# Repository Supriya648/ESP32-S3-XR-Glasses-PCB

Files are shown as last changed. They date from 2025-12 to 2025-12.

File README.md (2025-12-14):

# ESP32-S3-XR-Glasses-PCB
Custom PCB with ESP32-S3 camera module for AI/XR glasses
# ESP32-S3 Camera Resolution Performance Demo

## Project Overview
This project demonstrates video capture using an ESP32-S3-based camera system at multiple
resolutions to study trade-offs between image quality, frame rate, and memory usage.
The system is intended for compact, wearable AI/XR applications.

## Hardware
- ESP32-S3 MCU
- Camera module (OV2640 / OV3660)
- External PSRAM (on-chip)
- USB power and programming interface

## Software
- Arduino framework
- ESP32 camera driver

## Demo Description
Video clips were captured at different resolutions supported by the ESP32-S3:
- 320×240 (QVGA)
- 640×480 (VGA)
- 800×600 (SVGA)

Each configuration was evaluated for visual quality and approximate frame rate.

## Results
Lower resolutions achieved higher frame rates and stability, while higher resolutions
provided improved image detail at the cost of increased memory usage and reduced frame rate.

## Repository Structure
- firmware/: ESP32-S3 camera firmware
- hardware/: Schematic and PCB layout
- results/: Recorded video samples and performance logs
- report/: Final project report (PDF)

## Demo Video
YouTube link: [https://youtu.be/lZMv0Ex0UyA]

## Author
Supriya Ramaswamy  
EECE – Wireless & Network Engineering

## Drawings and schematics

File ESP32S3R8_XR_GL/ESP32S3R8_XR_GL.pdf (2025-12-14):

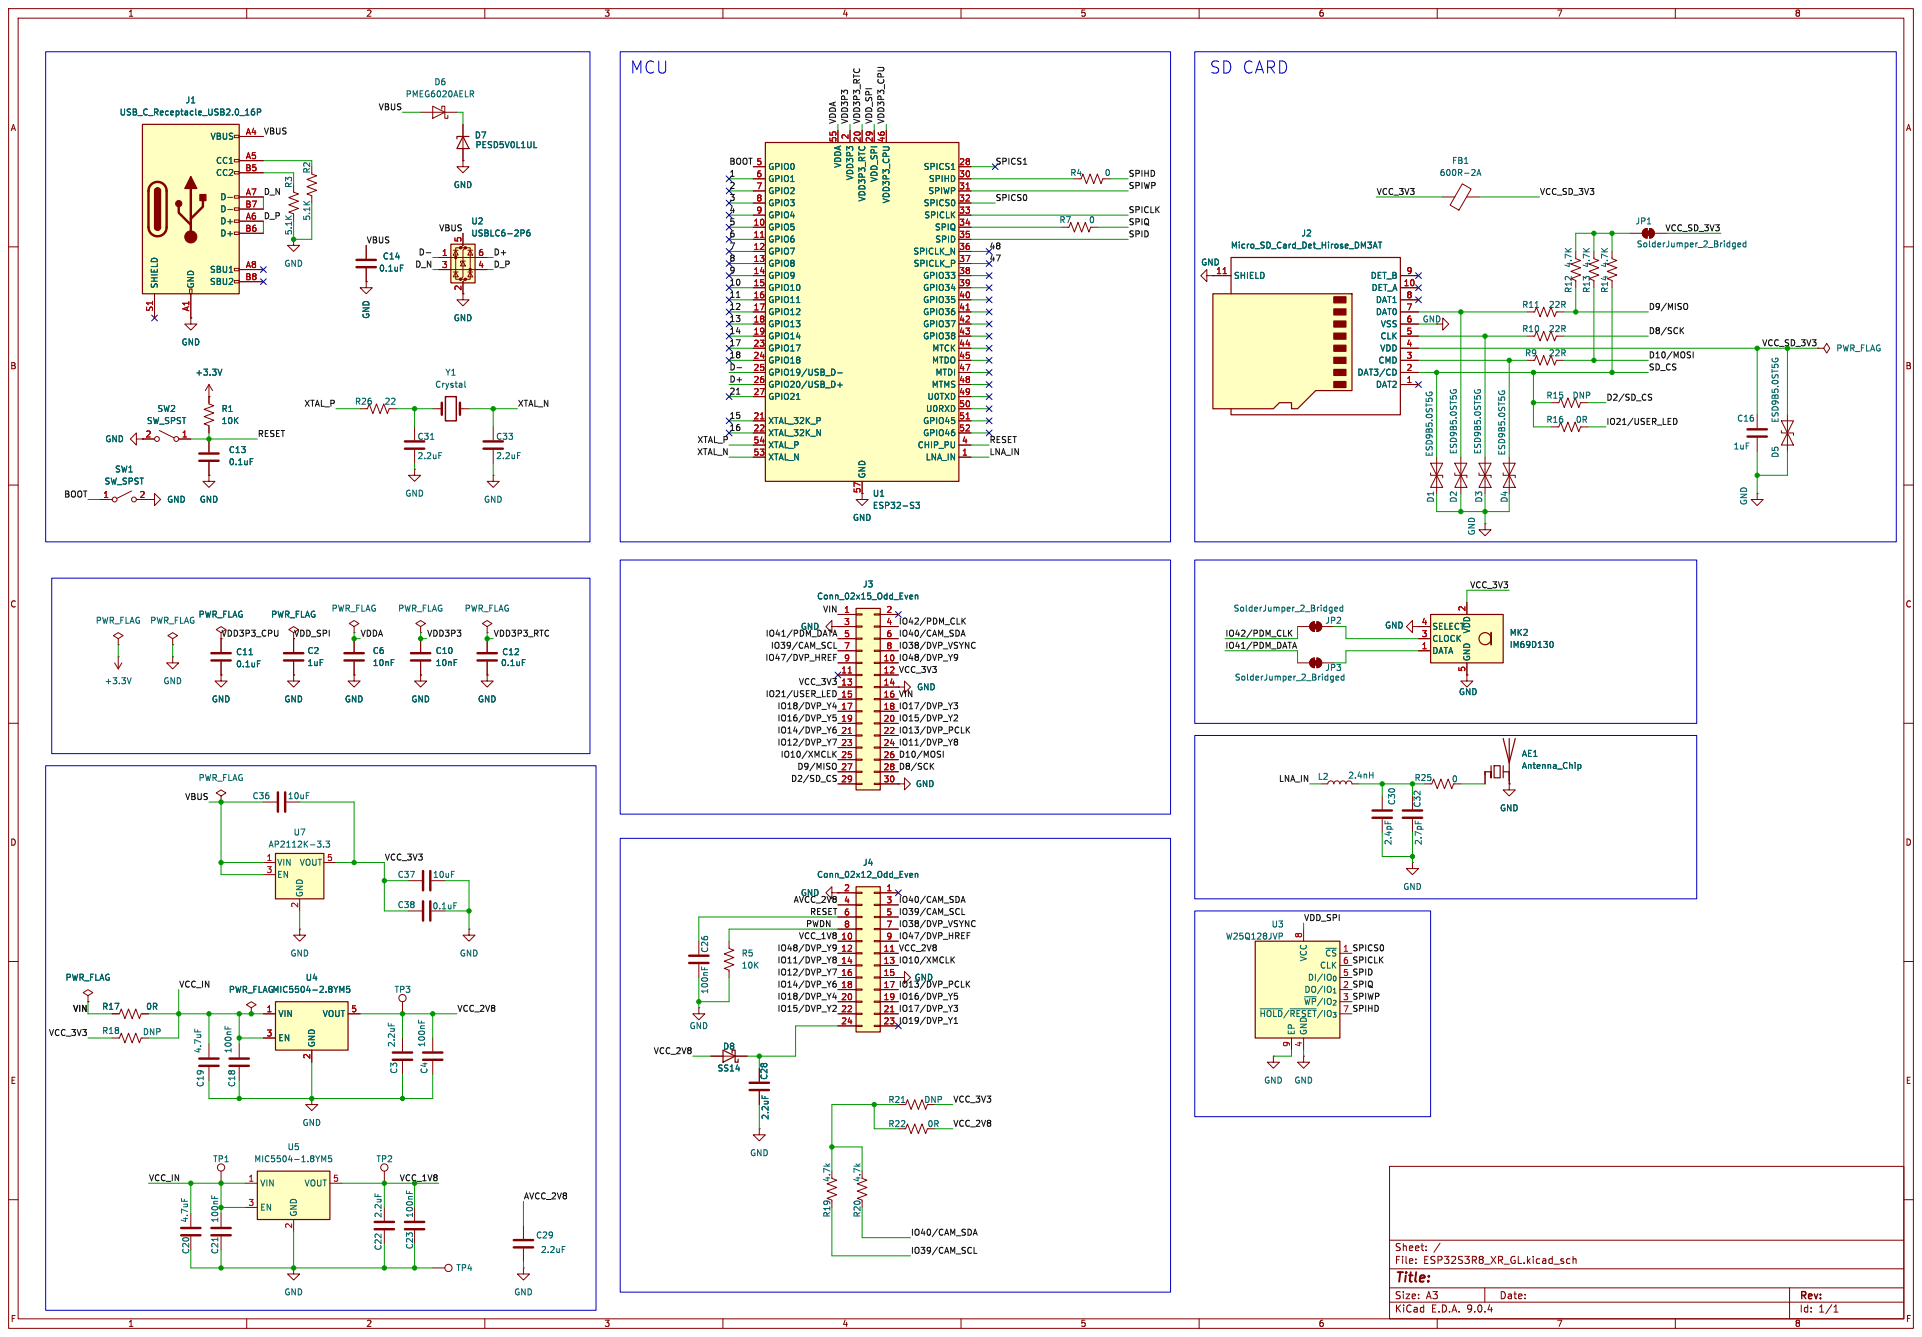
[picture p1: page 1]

2 VDD3P3_RTC 20 GND 57 VDD_SPI 29 VDD3P3_CPU 46 SPICS1 28 SPIHD 30 SPIWP 31 SPICS0 32 SPICLK 33 SPIQ 34 SPID 35 SPICLK_P 37 GPIO33 38 GPIO34 39 GPIO35 40 GPIO36 41 GPIO37 42 GPIO38 43 MTCK 44 MTDI 47 MTMS 48 U0TXD 49 U0RXD 50 GPIO46 52 CHIP_PU 4

5 SELECT 4 CLOCK 3 DATA 1 GND

2 VOUT 5 U4 MIC5504-2.8YM5 C19 4.7uF C18 100nF C3 2.2uF C4 100nF C21 100nF C23 100nF VIN 1 EN 3 GND

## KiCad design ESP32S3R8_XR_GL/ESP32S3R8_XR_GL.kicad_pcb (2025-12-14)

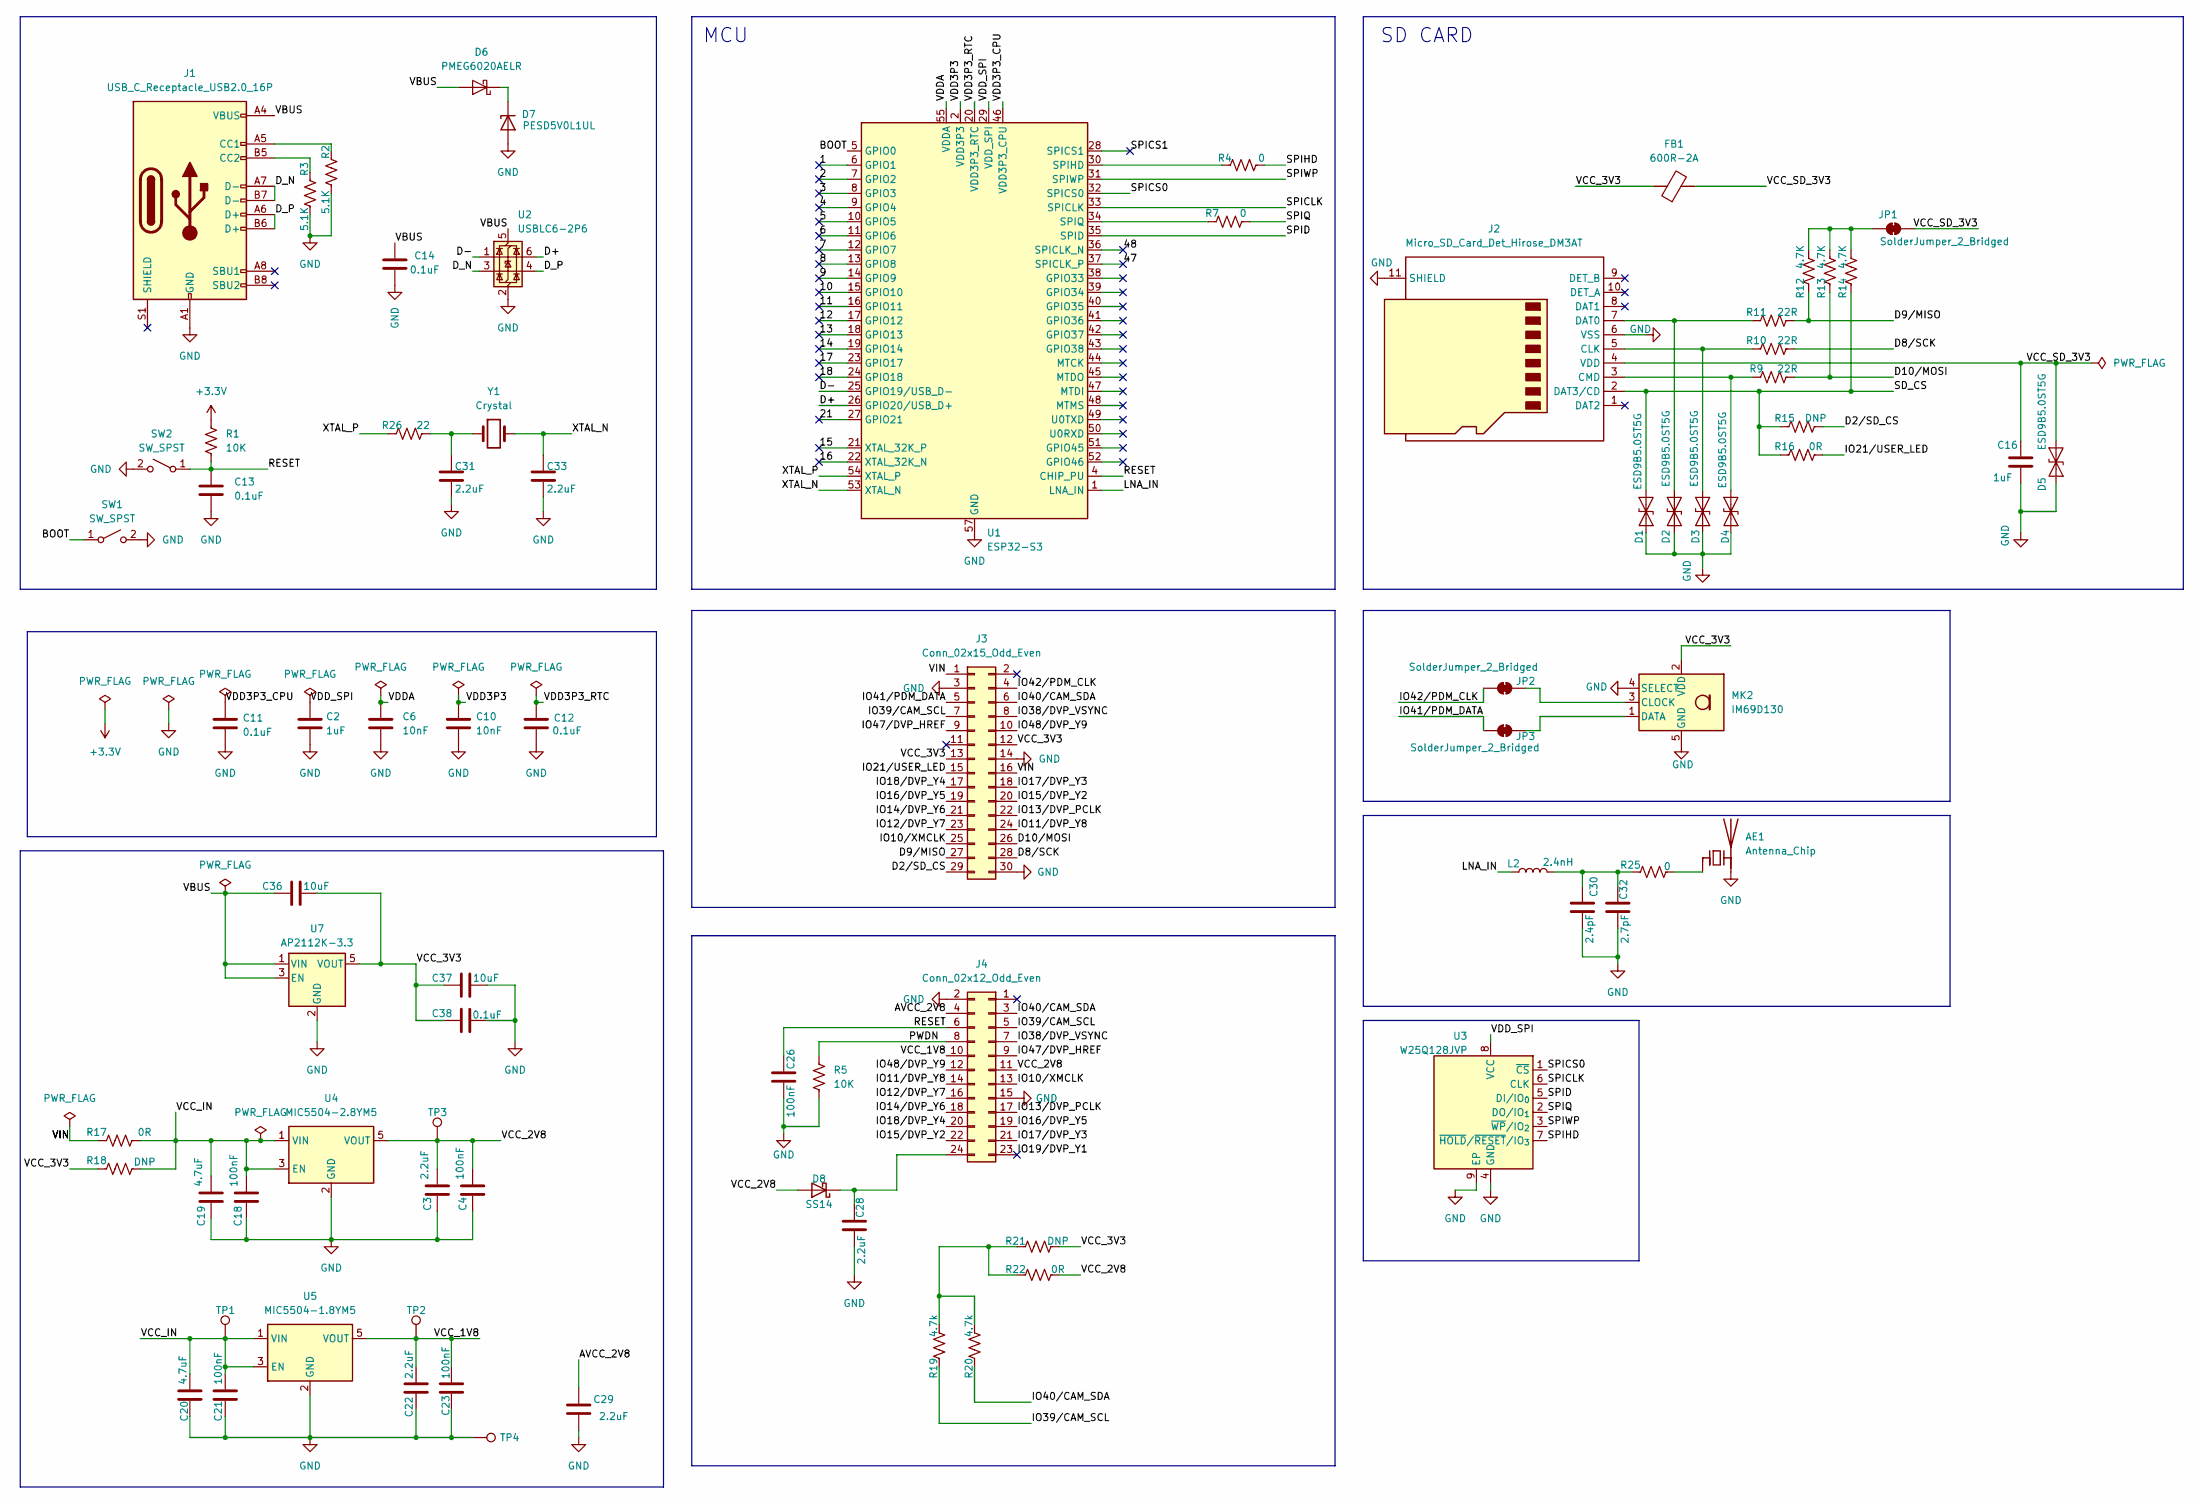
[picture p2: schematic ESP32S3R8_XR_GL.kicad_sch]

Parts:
AE1: Antenna_Chip; Johanson_2450AT18x100
C2, C16: 1uF; C_0603_1608Metric
C3, C22, C28, C29, C31, C33: 2.2uF; C_0603_1608Metric
C4, C18, C21, C23, C26: 100nF; C_0402_1005Metric
C6, C10: 10nF; C_0402_1005Metric
C11, C12, C13, C14, C38: 0.1uF; C_0402_1005Metric
C19, C20: 4.7uF; C_0603_1608Metric
C30: 2.4pF; C_0402_1005Metric
C32: 2.7pF; C_0402_1005Metric
C36, C37: 10uF; C_0805_2012Metric
D1, D2, D3, D4, D5: ESD9B5.0ST5G; D_SOD-923
D6: PMEG6020AELR; Nexperia_CFP3_SOD-123W
D7: PESD5V0L1UL; D_SOD-882
D8: SS14; D_SMA
FB1: 600R-2A; L_0805_2012Metric
J1: USB_C_Receptacle_USB2.0_16P; USB_C_Receptacle_GCT_USB4085
J2: Micro_SD_Card_Det_Hirose_DM3AT; microSD_HC_Hirose_DM3AT-SF-PEJM5
J3: Conn_02x15_Odd_Even; PinHeader_2x15_P2.54mm_Vertical
J4: Conn_02x12_Odd_Even; PinHeader_2x12_P2.54mm_Vertical
JP1, JP2, JP3: SolderJumper_2_Bridged; SolderJumper-2_P1.3mm_Bridged_RoundedPad1.0x1.5mm
L2: 2.4nH; L_0402_1005Metric
MK2: IM69D130; Infineon_PG-LLGA-5-1
R1, R5: 10K; R_0402_1005Metric
R2, R3: 5.1K; R_0402_1005Metric
R4, R7, R25: 0; R_0402_1005Metric
R9, R10, R11: 22R; R_0402_1005Metric
R12, R13, R14: 4.7K; R_0402_1005Metric
R15, R18, R21: DNP; R_0402_1005Metric
R16, R17, R22: 0R; R_0402_1005Metric
R19, R20: 4.7k; R_0402_1005Metric
R26: 22; R_0402_1005Metric
SW1, SW2: SW_SPST; SW_SPST_SKQG_WithStem
TP1, TP2, TP3, TP4: TestPoint; TestPoint_Pad_D1.0mm
U1: ESP32-S3; QFN-56-1EP_7x7mm_P0.4mm_EP4x4mm
U2: USBLC6-2P6; SOT-666
U3: W25Q128JVP; WSON-8-1EP_6x5mm_P1.27mm_EP3.4x4.3mm
U4: MIC5504-2.8YM5; SOT-23-5
U5: MIC5504-1.8YM5; SOT-23-5
U7: AP2112K-3.3; SOT-23-5
Y1: Crystal; Crystal_SMD_3225-4Pin_3.2x2.5mm

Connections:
+3.3V: R1.1
/1: U1.6 (GPIO1)
/2: U1.7 (GPIO2)
/3: U1.8 (GPIO3)
/4: U1.9 (GPIO4)
/5: U1.10 (GPIO5)
/6: U1.11 (GPIO6)
/7: U1.12 (GPIO7)
/8: U1.13 (GPIO8)
/9: U1.14 (GPIO9)
/10: U1.15 (GPIO10)
/11: U1.16 (GPIO11)
/12: U1.17 (GPIO12)
/13: U1.18 (GPIO13)
/14: U1.19 (GPIO14)
/15: U1.21 (XTAL_32K_P)
/16: U1.22 (XTAL_32K_N)
/17: U1.23 (GPIO17)
/18: U1.24 (GPIO18)
/21: U1.27 (GPIO21)
/47: U1.37 (SPICLK_P)
/48: U1.36 (SPICLK_N)
/AVCC_2V8: C29.1, J4.4
/BOOT: SW1.1 (A), U1.5 (GPIO0)
/D2/SD_CS: J3.29, R15.2
/D8/SCK: J3.28, R10.2
/D9/MISO: J3.27, R11.2, R12.1
/D10/MOSI: J3.26, R9.2, R13.1
/D+: U1.26 (GPIO20/USB_D+), U2.6 (I/O1)
/D-: U1.25 (GPIO19/USB_D-), U2.1 (I/O1)
/D_N: J1.A7 (D-), J1.B7 (D-), U2.3 (I/O2)
/D_P: J1.A6 (D+), J1.B6 (D+), U2.4 (I/O2)
/IO10/XMCLK: J3.25, J4.13
/IO11/DVP_Y8: J3.24, J4.14
/IO12/DVP_Y7: J3.23, J4.16
/IO13/DVP_PCLK: J3.22, J4.17
/IO14/DVP_Y6: J3.21, J4.18
/IO15/DVP_Y2: J3.20, J4.22
/IO16/DVP_Y5: J3.19, J4.19
/IO17/DVP_Y3: J3.18, J4.21
/IO18/DVP_Y4: J3.17, J4.20
/IO19/DVP_Y1: J4.23
/IO21/USER_LED: J3.15, R16.2
/IO38/DVP_VSYNC: J3.8, J4.7
/IO39/CAM_SCL: J3.7, J4.5, R19.1
/IO40/CAM_SDA: J3.6, J4.3, R20.1
/IO41/PDM_DATA: J3.5, JP3.2 (B)
/IO42/PDM_CLK: J3.4, JP2.2 (B)
/IO47/DVP_HREF: J3.9, J4.9
/IO48/DVP_Y9: J3.10, J4.12
/LNA_IN: L2.1, U1.1 (LNA_IN)
/PWDN: J4.8, R5.1
/RESET: C13.1, C26.1, J4.6, R1.2, SW2.1 (A), U1.4 (CHIP_PU)
/SD_CS: D1.2 (A2), J2.2 (DAT3/CD), R14.1, R15.1, R16.1
/SPICLK: U1.33 (SPICLK), U3.6 (CLK)
/SPICS0: U1.32 (SPICS0), U3.1 (~CS)
/SPICS1: U1.28 (SPICS1)
/SPID: U1.35 (SPID), U3.5 (DI/IO_{0})
/SPIHD: R4.2, U3.7 (~HOLD/~RESET/IO_{3})
/SPIQ: R7.2, U3.2 (DO/IO_{1})
/SPIWP: U1.31 (SPIWP), U3.3 (~WP/IO_{2})
/VBUS: C14.1, C36.1, D6.2 (A), J1.A4 (VBUS), J1.A9 (VBUS), J1.B4 (VBUS), J1.B9 (VBUS), U2.5 (VBUS), U7.1 (VIN), U7.3 (EN)
/VCC_1V8: C22.1, C23.1, J4.10, TP2.1, U5.5 (VOUT)
/VCC_2V8: C3.1, C4.1, D8.2 (A), J4.11, R22.2, TP3.1, U4.5 (VOUT)
/VCC_3V3: C36.2, C37.1, C38.1, FB1.1, J3.12, J3.13, MK2.2 (VDD), R18.1, R21.2, U7.5 (VOUT)
/VCC_IN: C18.1, C19.1, C20.1, C21.1, R17.2, R18.2, TP1.1, U4.1 (VIN), U4.3 (EN), U5.1 (VIN), U5.3 (EN)
/VCC_SD_3V3: C16.1, D5.2 (A2), FB1.2, J2.4 (VDD), JP1.2 (B)
/VDD3P3: C10.1, U1.2 (VDD3P3), U1.3 (VDD3P3)
/VDD3P3_CPU: C11.1, U1.46 (VDD3P3_CPU)
/VDD3P3_RTC: C12.1, U1.20 (VDD3P3_RTC)
/VDDA: C6.1, U1.55 (VDDA), U1.56 (VDDA)
/VDD_SPI: C2.1, U1.29 (VDD_SPI), U3.8 (VCC)
/VIN: J3.1, J3.16, R17.1
/XTAL_N: C33.1, U1.53 (XTAL_N), Y1.2
/XTAL_P: R26.1, U1.54 (XTAL_P)
GND: AE1.2 (PCB_Trace), C2.2, C3.2, C4.2, C6.2, C10.2, C11.2, C12.2, C13.2, C14.2, C16.2, C18.2, C19.2, C20.2, C21.2, C22.2, C23.2, C26.2, C28.2, C29.2, C30.2, C31.2, C32.2, C33.2, C37.2, C38.2, D1.1 (A1), D2.1 (A1), D3.1 (A1), D4.1 (A1), D5.1 (A1), D7.2 (A), J1.A1 (GND), J1.A12 (GND), J1.B1 (GND), J1.B12 (GND), J2.6 (VSS), J2.11 (SHIELD), J3.3, J3.14, J3.30, J4.2, J4.15, MK2.4 (SELECT), MK2.5 (GND), R2.2, R3.2, R5.2, SW1.2 (B), SW2.2 (B), TP4.1, U1.57 (GND), U2.2 (GND), U3.4 (GND), U3.9 (EP), U4.2 (GND), U5.2 (GND), U7.2 (GND)
unnamed: AE1.1 (FEED), R25.1
unnamed: C30.1, C32.1, L2.2, R25.2
unnamed: C31.1, R26.2, Y1.1
unnamed: D2.2 (A2), J2.7 (DAT0), R11.1
unnamed: D3.2 (A2), J2.5 (CLK), R10.1
unnamed: D4.2 (A2), J2.3 (CMD), R9.1
unnamed: D6.1 (K), D7.1 (K)
unnamed: C28.1, D8.1 (K), J4.24
unnamed: J1.A5 (CC1), R2.1
unnamed: J1.B5 (CC2), R3.1
unnamed: JP1.1 (A), R12.2, R13.2, R14.2
unnamed: JP2.1 (A), MK2.3 (CLOCK)
unnamed: JP3.1 (A), MK2.1 (DATA)
unnamed: R19.2, R20.2, R21.1, R22.1
unnamed: R4.1, U1.30 (SPIHD)
unnamed: R7.1, U1.34 (SPIQ)

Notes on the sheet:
MCU
SD CARD

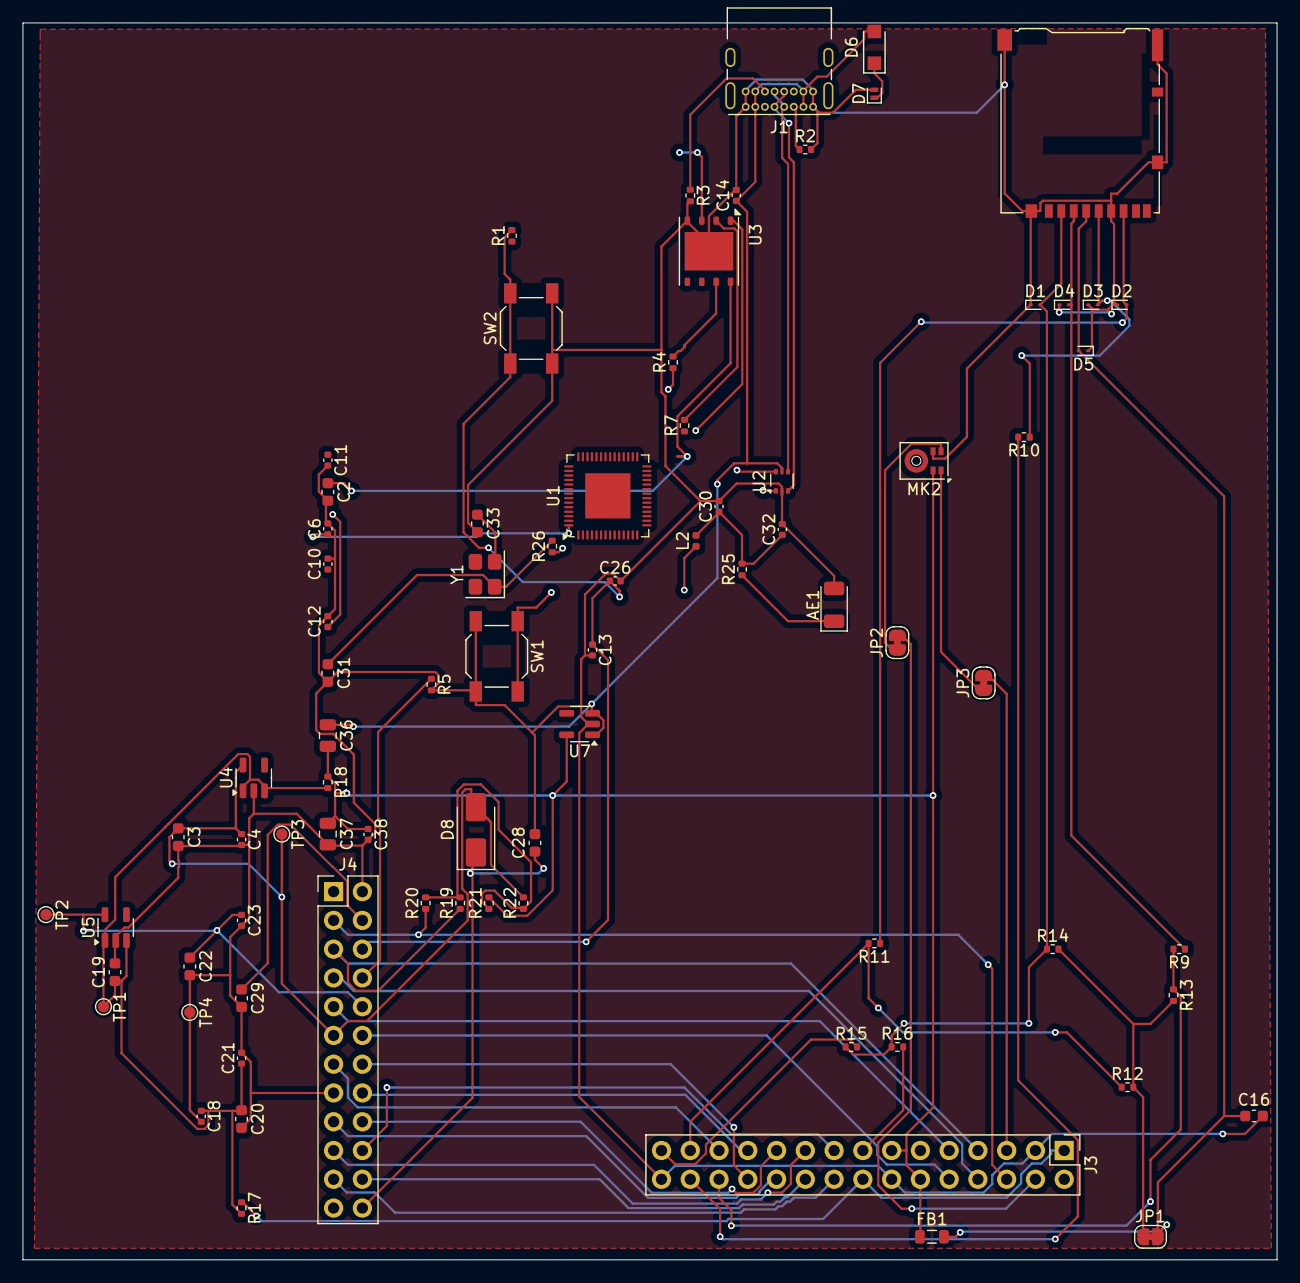
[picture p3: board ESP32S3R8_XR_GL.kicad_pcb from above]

Board: 2 copper layers, 110.7 x 109.2 mm, 80 parts (0 on the bottom side), 68 nets.

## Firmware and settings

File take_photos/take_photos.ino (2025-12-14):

#include "esp_camera.h"
#include "FS.h"
#include "SD.h"
#include "SPI.h"

#define CAMERA_MODEL_XIAO_ESP32S3 // Has PSRAM

#include "camera_pins.h"

unsigned long lastCaptureTime = 0; // Last shooting time
int imageCount = 1;                // File Counter
bool camera_sign = false;          // Check camera status
bool sd_sign = false;              // Check sd status

// Save pictures to SD card
void photo_save(const char * fileName) {
  // Take a photo
  camera_fb_t *fb = esp_camera_fb_get();
  if (!fb) {
    Serial.println("Failed to get camera frame buffer");
    return;
  }
  // Save photo to file
  writeFile(SD, fileName, fb->buf, fb->len);
  
  // Release image buffer
  esp_camera_fb_return(fb);

  Serial.println("Photo saved to file");
}

// SD card write file
void writeFile(fs::FS &fs, const char * path, uint8_t * data, size_t len){
    Serial.printf("Writing file: %s\r\n", path);

    File file = fs.open(path, FILE_WRITE);
    if(!file){
        Serial.println("Failed to open file for writing");
        return;
    }
    if(file.write(data, len) == len){
        Serial.println("File written");
    } else {
        Serial.println("Write failed");
    }
    file.close();
}

void setup() {
  Serial.begin(115200);
  while(!Serial); // When the serial monitor is turned on, the program starts to execute

  camera_config_t config;
  config.ledc_channel = LEDC_CHANNEL_0;
  config.ledc_timer = LEDC_TIMER_0;
  config.pin_d0 = Y2_GPIO_NUM;
  config.pin_d1 = Y3_GPIO_NUM;
  config.pin_d2 = Y4_GPIO_NUM;
  config.pin_d3 = Y5_GPIO_NUM;
  config.pin_d4 = Y6_GPIO_NUM;
  config.pin_d5 = Y7_GPIO_NUM;
  config.pin_d6 = Y8_GPIO_NUM;
  config.pin_d7 = Y9_GPIO_NUM;
  config.pin_xclk = XCLK_GPIO_NUM;
  config.pin_pclk = PCLK_GPIO_NUM;
  config.pin_vsync = VSYNC_GPIO_NUM;
  config.pin_href = HREF_GPIO_NUM;
  config.pin_sscb_sda = SIOD_GPIO_NUM;
  config.pin_sscb_scl = SIOC_GPIO_NUM;
  config.pin_pwdn = PWDN_GPIO_NUM;
  config.pin_reset = RESET_GPIO_NUM;
  config.xclk_freq_hz = 20000000;
  config.frame_size = FRAMESIZE_UXGA;
  config.pixel_format = PIXFORMAT_JPEG; // for streaming
  config.grab_mode = CAMERA_GRAB_WHEN_EMPTY;
  config.fb_location = CAMERA_FB_IN_PSRAM;
  config.jpeg_quality = 12;
  config.fb_count = 1;
  
  // if PSRAM IC present, init with UXGA resolution and higher JPEG quality
  //                      for larger pre-allocated frame buffer.
  if(config.pixel_format == PIXFORMAT_JPEG){
    if(psramFound()){
      config.jpeg_quality = 10;
      config.fb_count = 2;
      config.grab_mode = CAMERA_GRAB_LATEST;
    } else {
      // Limit the frame size when PSRAM is not available
      config.frame_size = FRAMESIZE_SVGA;
      config.fb_location = CAMERA_FB_IN_DRAM;
    }
  } else {
    // Best option for face detection/recognition
    config.frame_size = FRAMESIZE_240X240;
#if CONFIG_IDF_TARGET_ESP32S3
    config.fb_count = 2;
#endif
  }

  // camera init
  esp_err_t err = esp_camera_init(&config);
  if (err != ESP_OK) {
    Serial.printf("Camera init failed with error 0x%x", err);
    return;
  }
  
  camera_sign = true; // Camera initialization check passes

  // Initialize SD card
  if(!SD.begin(21)){
    Serial.println("Card Mount Failed");
    return;
  }
  uint8_t cardType = SD.cardType();

  // Determine if the type of SD card is available
  if(cardType == CARD_NONE){
    Serial.println("No SD card attached");
    return;
  }

  Serial.print("SD Card Type: ");
  if(cardType == CARD_MMC){
    Serial.println("MMC");
  } else if(cardType == CARD_SD){
    Serial.println("SDSC");
  } else if(cardType == CARD_SDHC){
    Serial.println("SDHC");
  } else {
    Serial.println("UNKNOWN");
  }

  sd_sign = true; // sd initialization check passes

  Serial.println("Photos will begin in one minute, please be ready.");
}

void loop() {
  // Camera & SD available, start taking pictures
  if(camera_sign && sd_sign){
    // Get the current time
    unsigned long now = millis();
  
    //If it has been more than 1 minute since the last shot, take a picture and save it to the SD card
    if ((now - lastCaptureTime) >= 10000) {
      char filename[32];
      sprintf(filename, "/image%d.jpg", imageCount);
      photo_save(filename);
      Serial.printf("Saved picture: %s\r\n", filename);
      Serial.println("Photos will begin in one minute, please be ready.");
      imageCount++;
      lastCaptureTime = now;
    }
  }
}
